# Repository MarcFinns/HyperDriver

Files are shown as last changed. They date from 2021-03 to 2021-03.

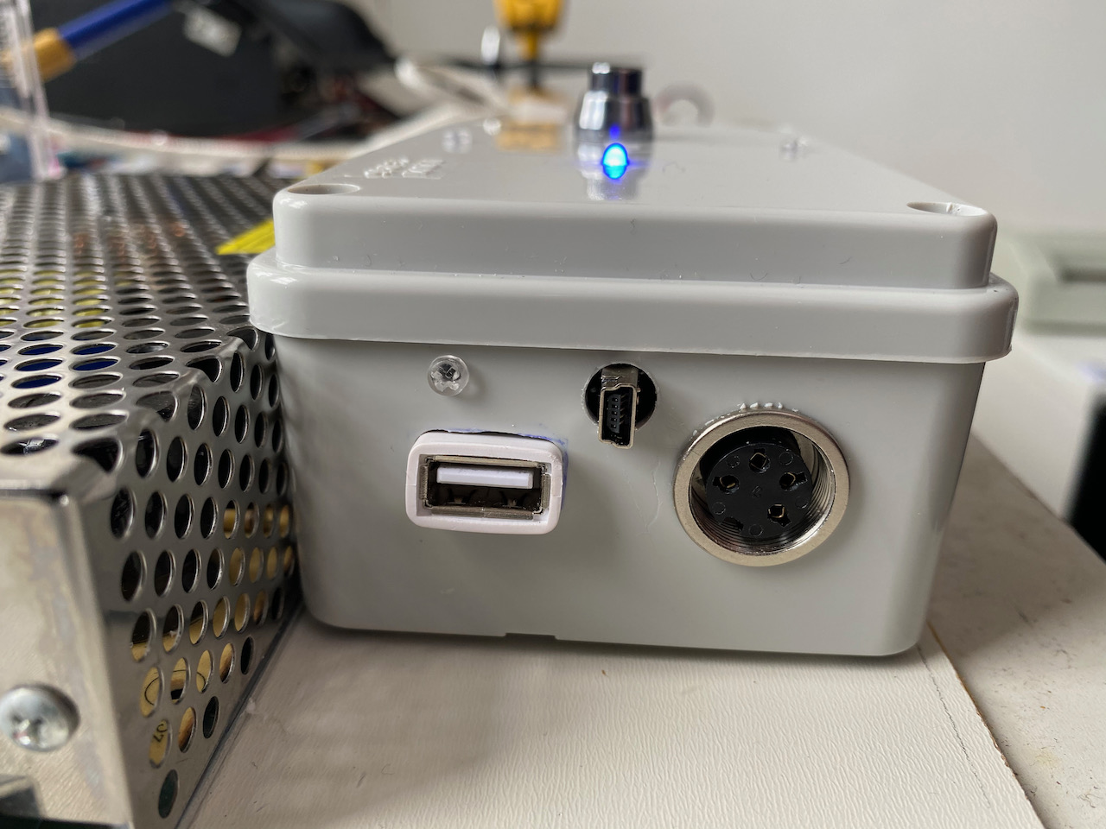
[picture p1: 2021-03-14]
Pictures/Box connections.jpeg

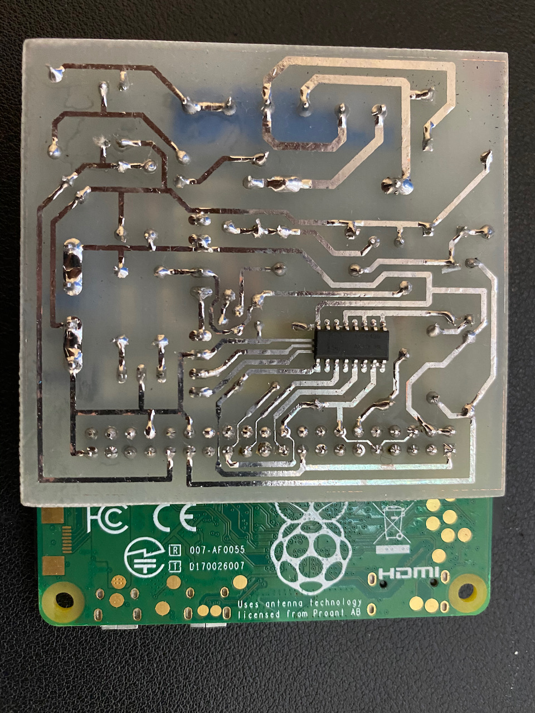
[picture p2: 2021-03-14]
Pictures/Board back.jpeg

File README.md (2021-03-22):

# HyperDriver
LED driver and power board for Hyperion (DYI Ambilight)

See short video: https://www.youtube.com/watch?v=JoaK5aRHBMA

After setting up hyperion I was annoyed by starting/stopping it manually every time.
My weekend project was to build a proper solution - with components I had in the drawer, which might explain some weird design choices.

The board does the following:

* Connects as a PI hat
* Powers the PI and the LED strip with the same power supply
* Provides 5V drivers / level adaptation for the APA 102 LED stripe
* Allows to turn the PI on by pushing a button
* With the same button, triggers a proper shutdown (no abrupt power cut)
* Connects to TV via USB and can start the PI when the TV turns on
* The PI can automatically shutdown when TV goes off (immediately or after X minutes)
* If the automatic turn on from TV is triggered, the PI can still be shut down via the button
* A 5V socket is available for a small fan, in case

The On/Off function is proper, meaning the power supply is truly disconnected from the mains when off.
I made sure that the PCB is single side and doable at home with some medium skills (e.g. i made it with toner transfer). 
I could not avoid one SMD but only because I did not have the through-hole part in the drawer. Convertinf the PCB to through hole is trivial.
The whole thing fits in a small electric junction box. See pictures.

**IMPORTANT DISCLAIMER:**<BR>
* This is **NOT** your typical 5V Arduino project. <BR>
* It is **NOT** breadboard friendly.<BR>
* Make it **ONLY** if you know what you are doing.<BR>
* Danger of electrocution

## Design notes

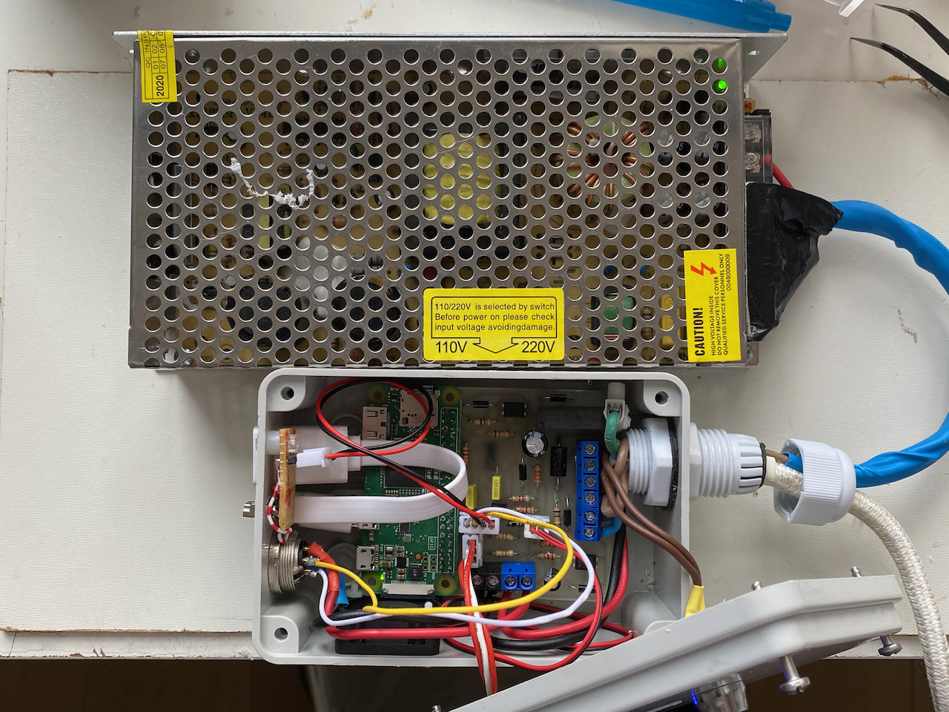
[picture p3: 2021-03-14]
Pictures/Box open and power supply.jpeg

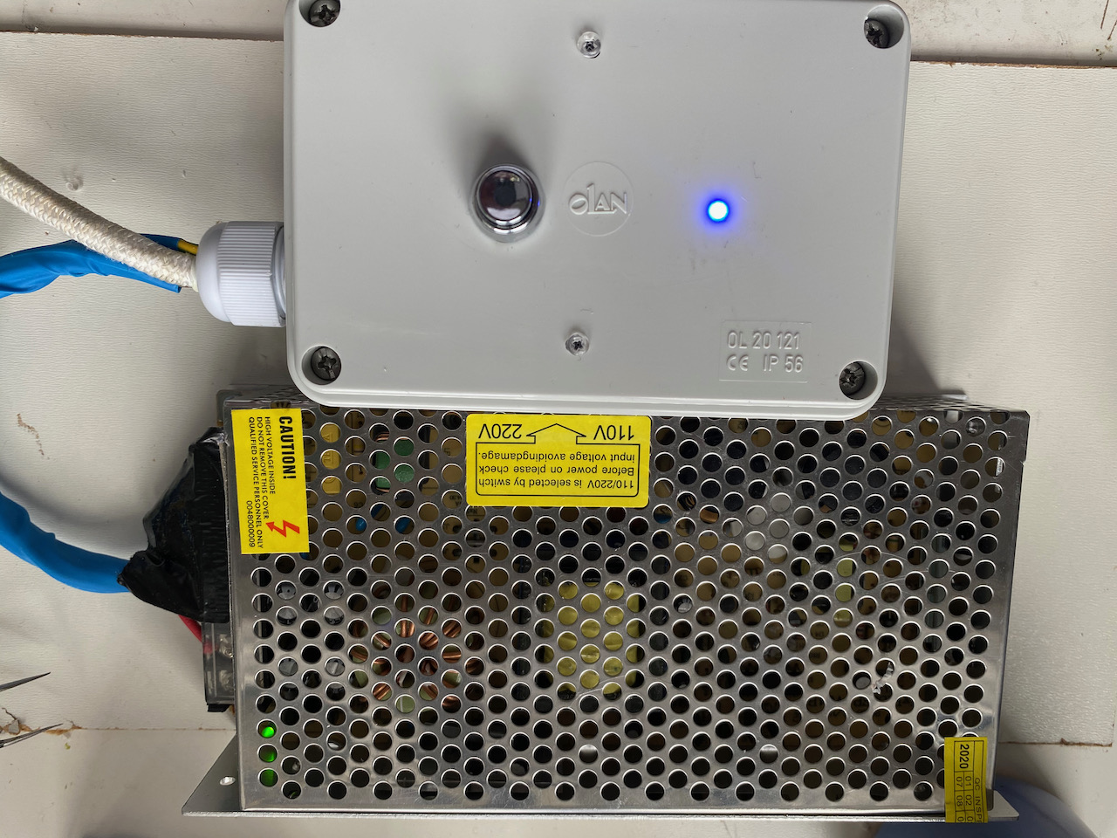
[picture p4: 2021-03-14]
Pictures/Box and power supply.jpeg

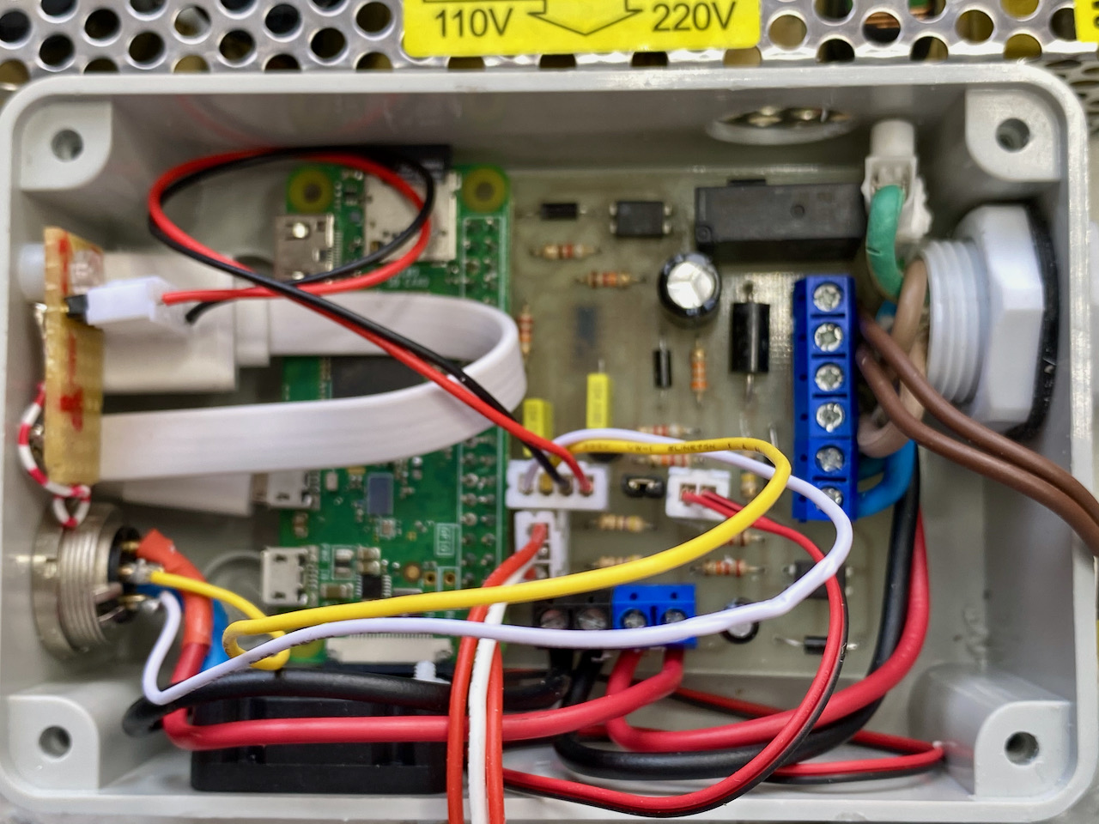
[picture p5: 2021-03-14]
Pictures/Box inside.jpeg

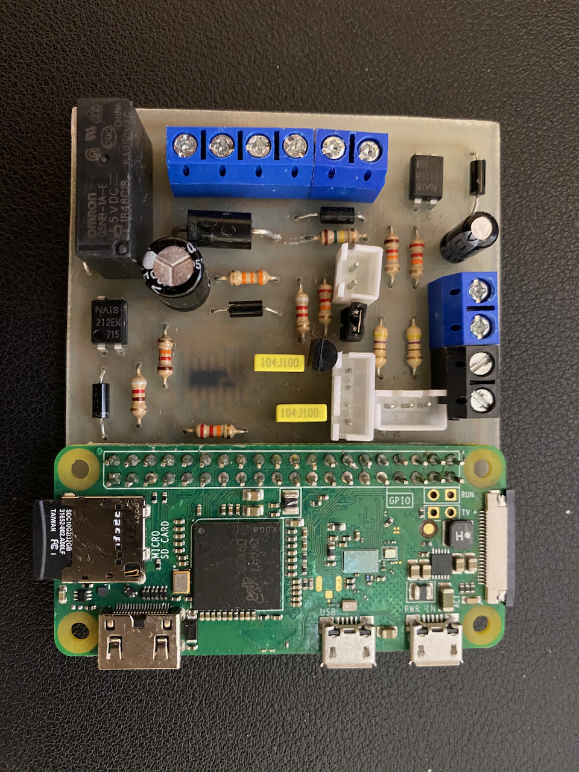
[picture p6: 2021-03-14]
Pictures/Board front.jpeg

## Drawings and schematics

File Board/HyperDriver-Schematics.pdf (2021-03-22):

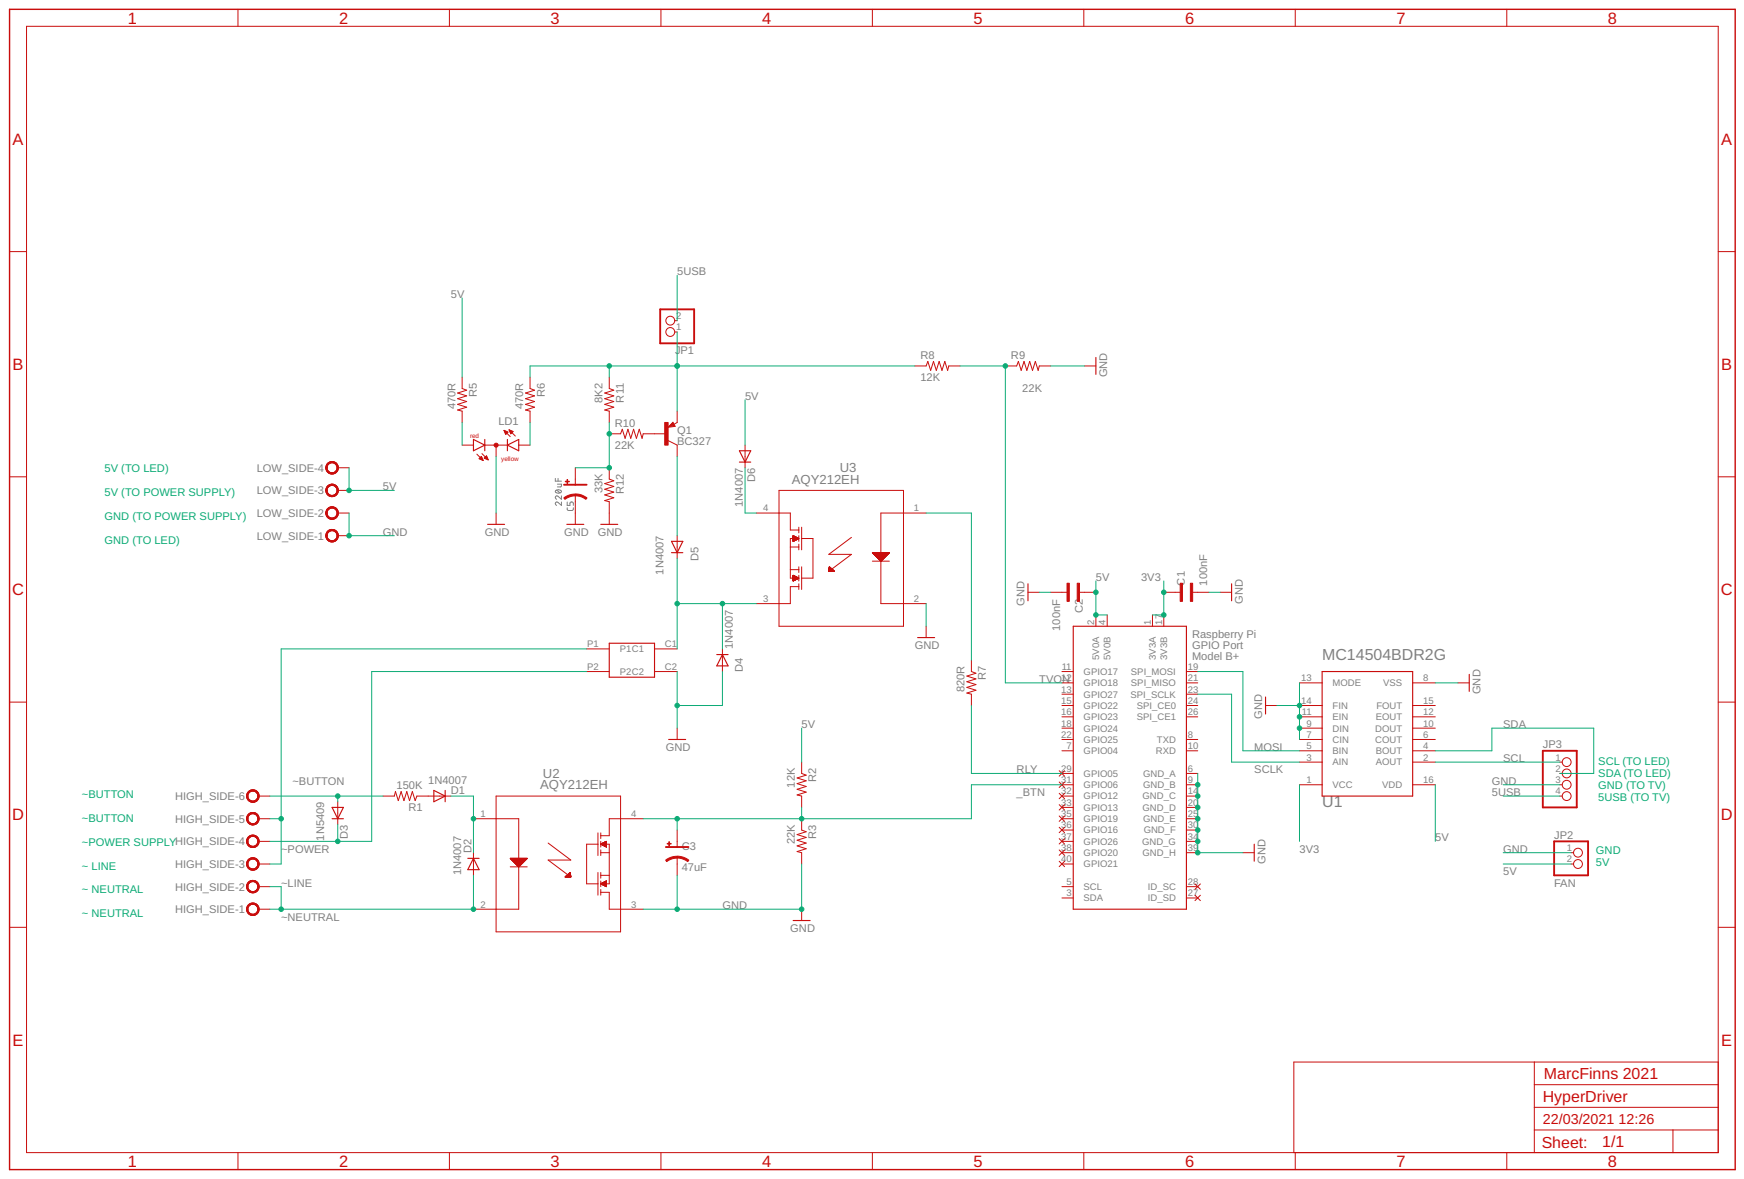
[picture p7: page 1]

5V (TO LED)
5V (TO POWER SUPPLY)
GND (TO POWER SUPPLY)
GND (TO LED)

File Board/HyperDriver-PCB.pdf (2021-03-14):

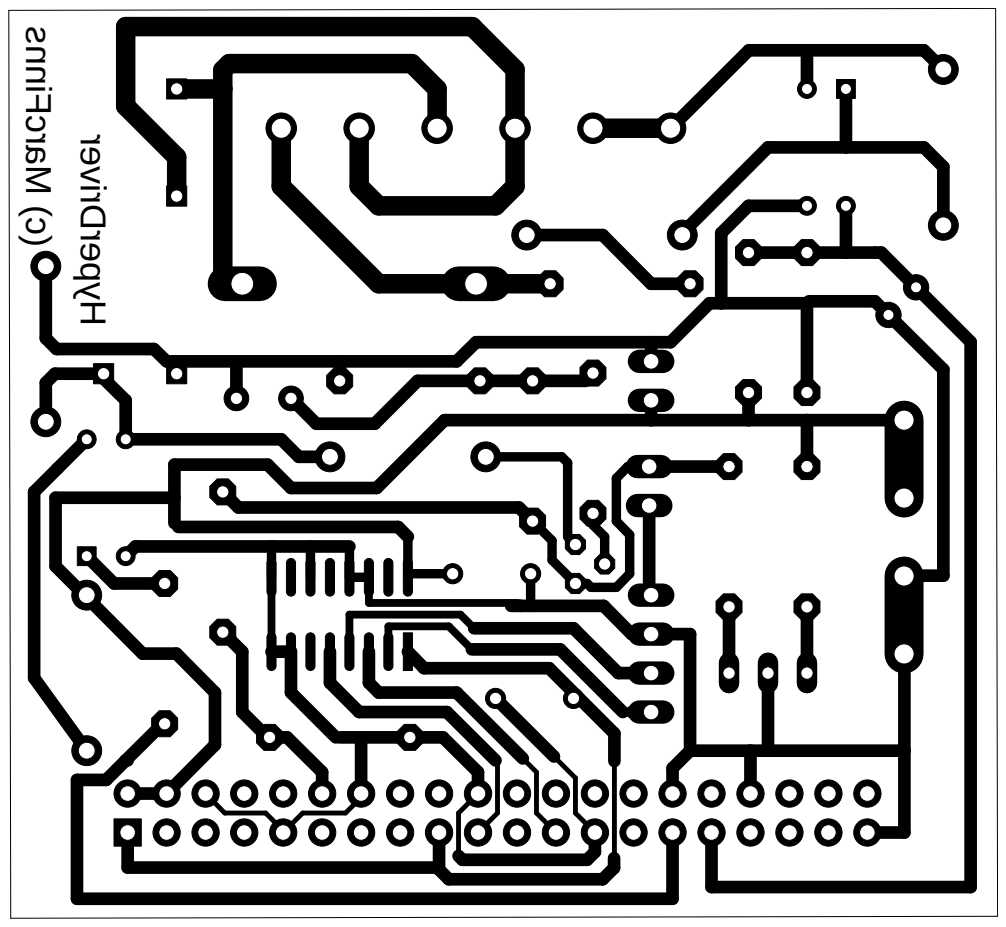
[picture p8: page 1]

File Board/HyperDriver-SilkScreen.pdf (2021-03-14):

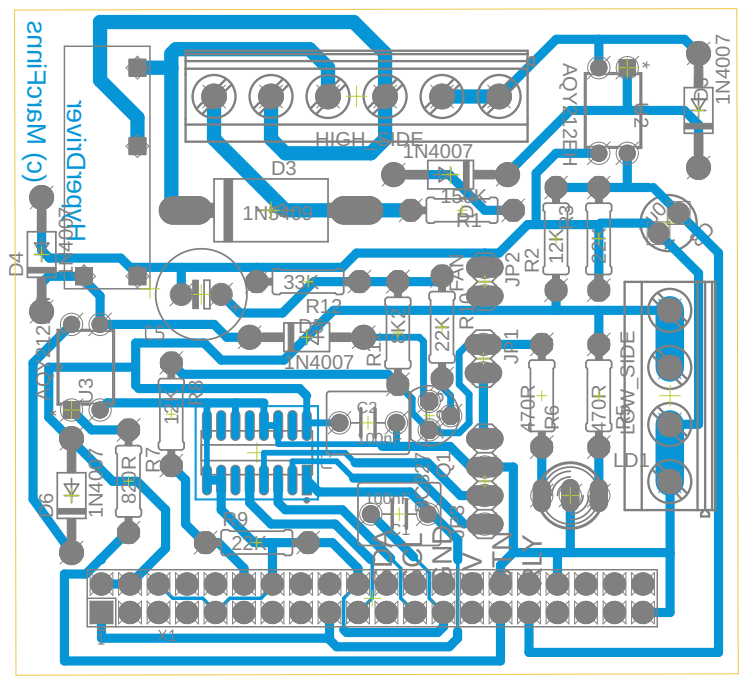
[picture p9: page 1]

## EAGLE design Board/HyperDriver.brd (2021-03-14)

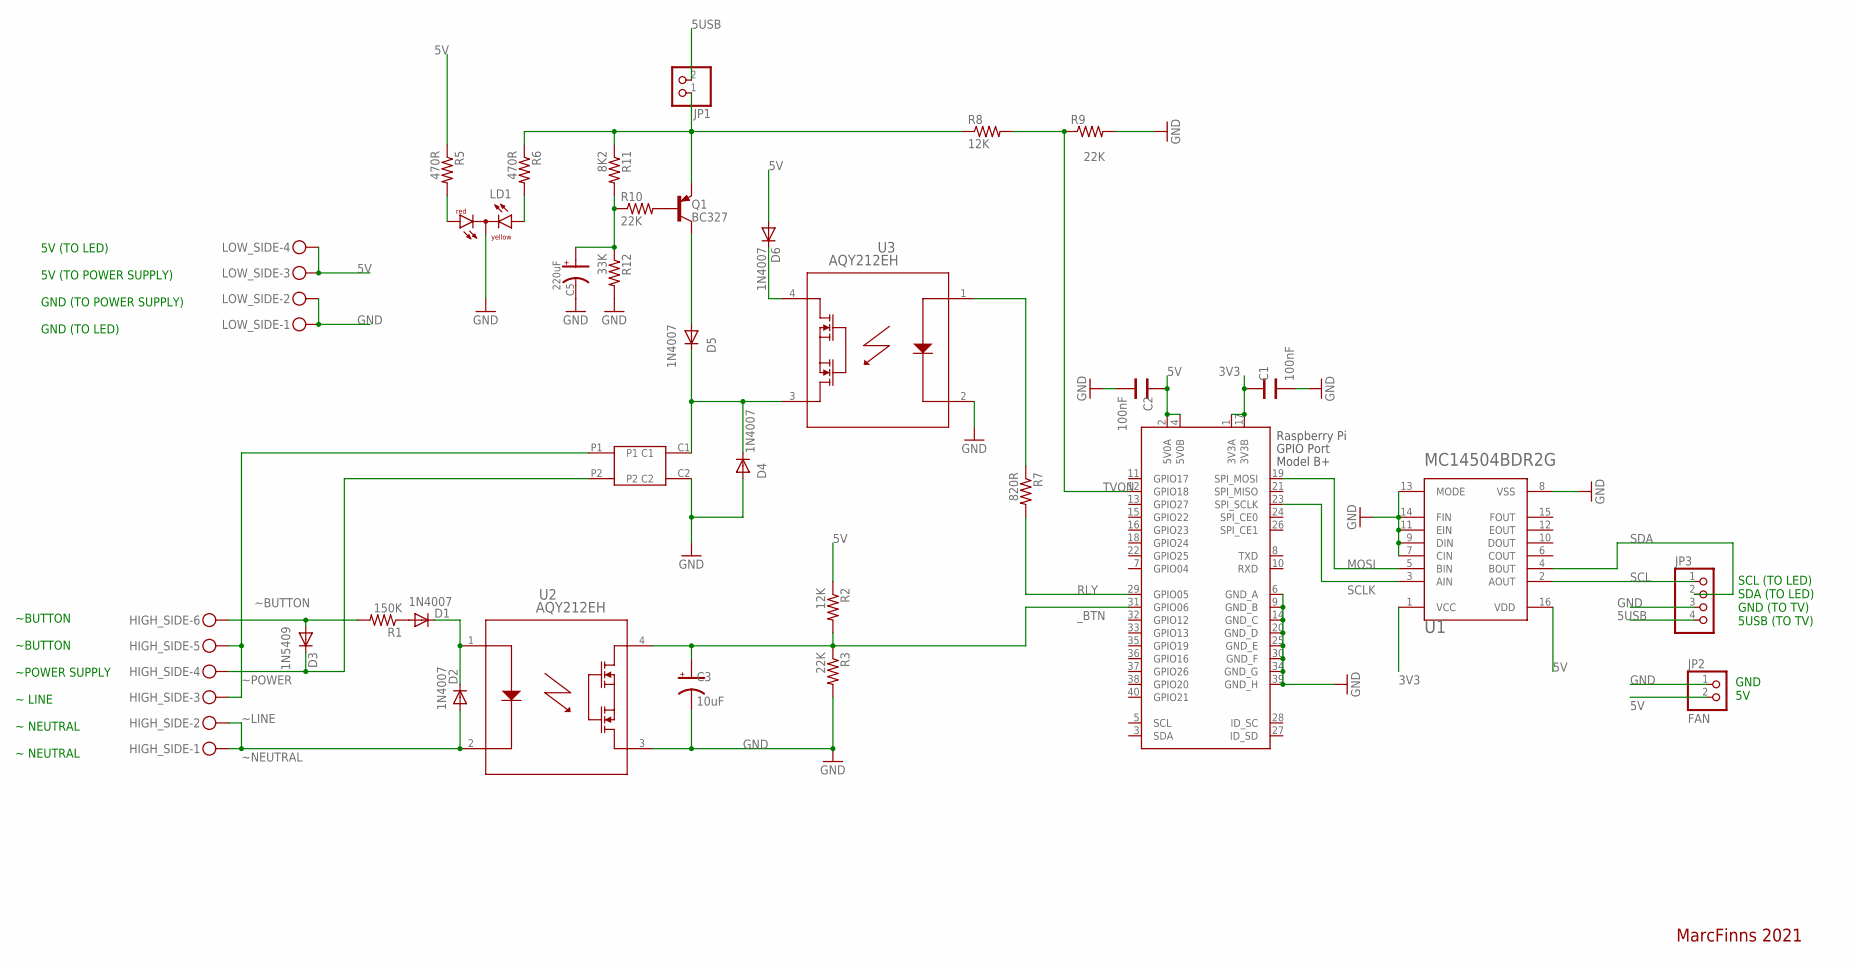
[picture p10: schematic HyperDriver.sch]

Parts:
C1, C2: 100nF; CAP-055X070
C3: 10uF; CAP-POL-025X50
C5: 220uF; CAP-POL-E3,5-8
D1, D2, D4, D5, D6: 1N4007; DO41-10
D3: 1N5409; DO201-15
G5NB_RELAY1: OMRON_G5NB_RELAY; G5NB_RELAY
HIGH_SIDE: MKDSN1,5/6-5,08
JP1: PINHD-1X2; 1X02
JP2: FAN; 1X02
JP3: PINHD-1X4; 1X04
LD1: DUOLED-RY-C; DUOLED-C-5MM
LOW_SIDE: MKDSN1,5/4-5,08
Q1: BC327; TO92
R1: 150K; 0207/9
R2, R8: 12K; 0207/9
R3, R9, R10: 22K; 0207/9
R5, R6: 470R; 0207/9
R7: 820R; 0207/9
R11: 8K2; 0207/9
R12: 33K; 0207/9
U1: ON_SEMICONDUCTOR_MC14504BDR2GON_SEMICONDUCTOR_MC1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; ON_SEMICONDUCTOR_MC14504BDR2G_1
U2, U3: AQY212EH; PAN_AQY21-DIP4_PAN
X1: RASPI_GPIO_B+#_PIN; RASPI_GPIO_B+_PIN

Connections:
3V3: C1.1, U1.1 (VCC), X1.1 (3V3A), X1.17 (3V3B)
5USB: JP1.2, JP3.4
5V: C2.1, D6.A, JP2.2, LOW_SIDE.3, LOW_SIDE.4, R2.1, R5.1, U1.16 (VDD), X1.2 (5V0A), X1.4 (5V0B)
GND: C1.2, C2.2, C3.C, C5.C, D4.A, G5NB_RELAY1.C2, JP2.1, JP3.3, LD1.C, LOW_SIDE.1, LOW_SIDE.2, R3.2, R9.2, R12.2, U1.7 (CIN), U1.8 (VSS), U1.9 (DIN), U1.11 (EIN), U1.13 (MODE), U1.14 (FIN), U2.3, U3.2, X1.6 (GND_A), X1.9 (GND_B), X1.14 (GND_C), X1.20 (GND_D), X1.25 (GND_E), X1.30 (GND_F), X1.34 (GND_G), X1.39 (GND_H)
J_5USB: JP1.1, Q1.1 (E), R6.1, R8.1, R11.1
MOSI: U1.5 (BIN), X1.19 (SPI_MOSI)
unnamed: LD1.AR, R5.2
unnamed: LD1.AX (AY), R6.2
unnamed: D6.C, U3.4
unnamed: Q1.2 (B), R10.2
unnamed: C5.A, R10.1, R11.2, R12.1
unnamed: D1.C, D2.C, U2.1
unnamed: R7.1, U3.1
unnamed: D4.C, D5.C, G5NB_RELAY1.C1, U3.3
unnamed: D5.A, Q1.3 (C)
unnamed: D1.A, R1.1
RLY: R7.2, X1.29 (GPIO05)
SCL: JP3.1, U1.2 (AOUT)
SCLK: U1.3 (AIN), X1.23 (SPI_SCLK)
SDA: JP3.2, U1.4 (BOUT)
TVON: R8.2, R9.1, X1.12 (GPIO18)
_BTN: C3.A, R2.2, R3.1, U2.4, X1.31 (GPIO06)
~BUTTON: D3.A, HIGH_SIDE.6, R1.2
~LINE: G5NB_RELAY1.P1, HIGH_SIDE.3, HIGH_SIDE.5
~NEUTRAL: D2.A, HIGH_SIDE.1, HIGH_SIDE.2, U2.2
~POWER: D3.C, G5NB_RELAY1.P2, HIGH_SIDE.4

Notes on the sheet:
SCL (TO LED) SDA (TO LED) GND (TO TV) 5USB (TO TV)
GND 5V
~BUTTON ~BUTTON ~POWER SUPPLY ~ LINE ~ NEUTRAL ~ NEUTRAL
5V (TO LED) 5V (TO POWER SUPPLY) GND (TO POWER SUPPLY) GND (TO LED)
MarcFinns 2021

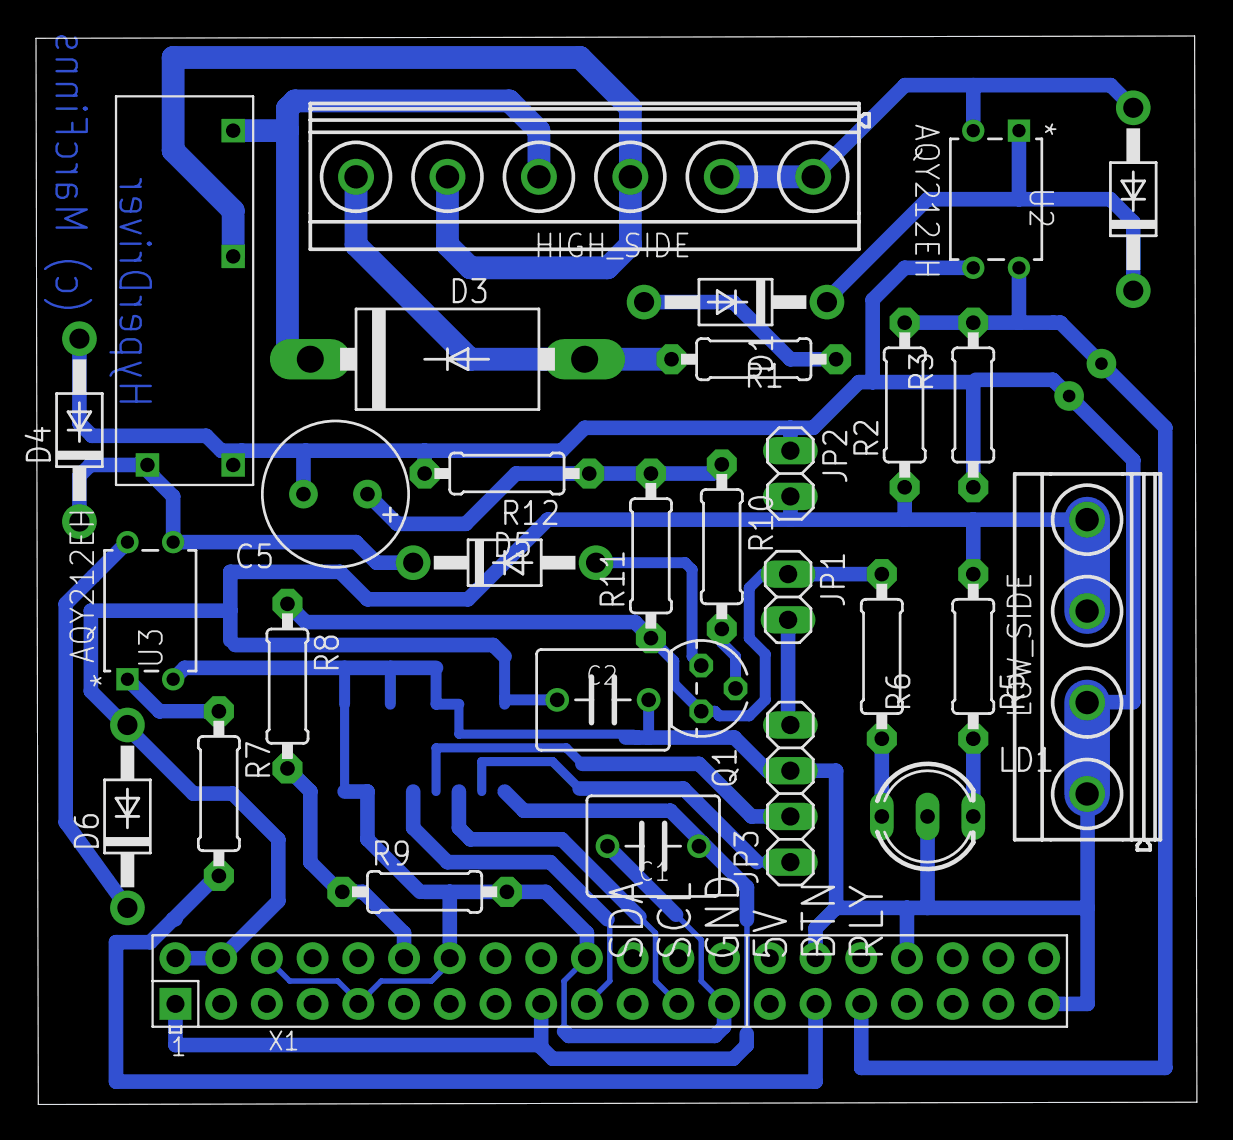
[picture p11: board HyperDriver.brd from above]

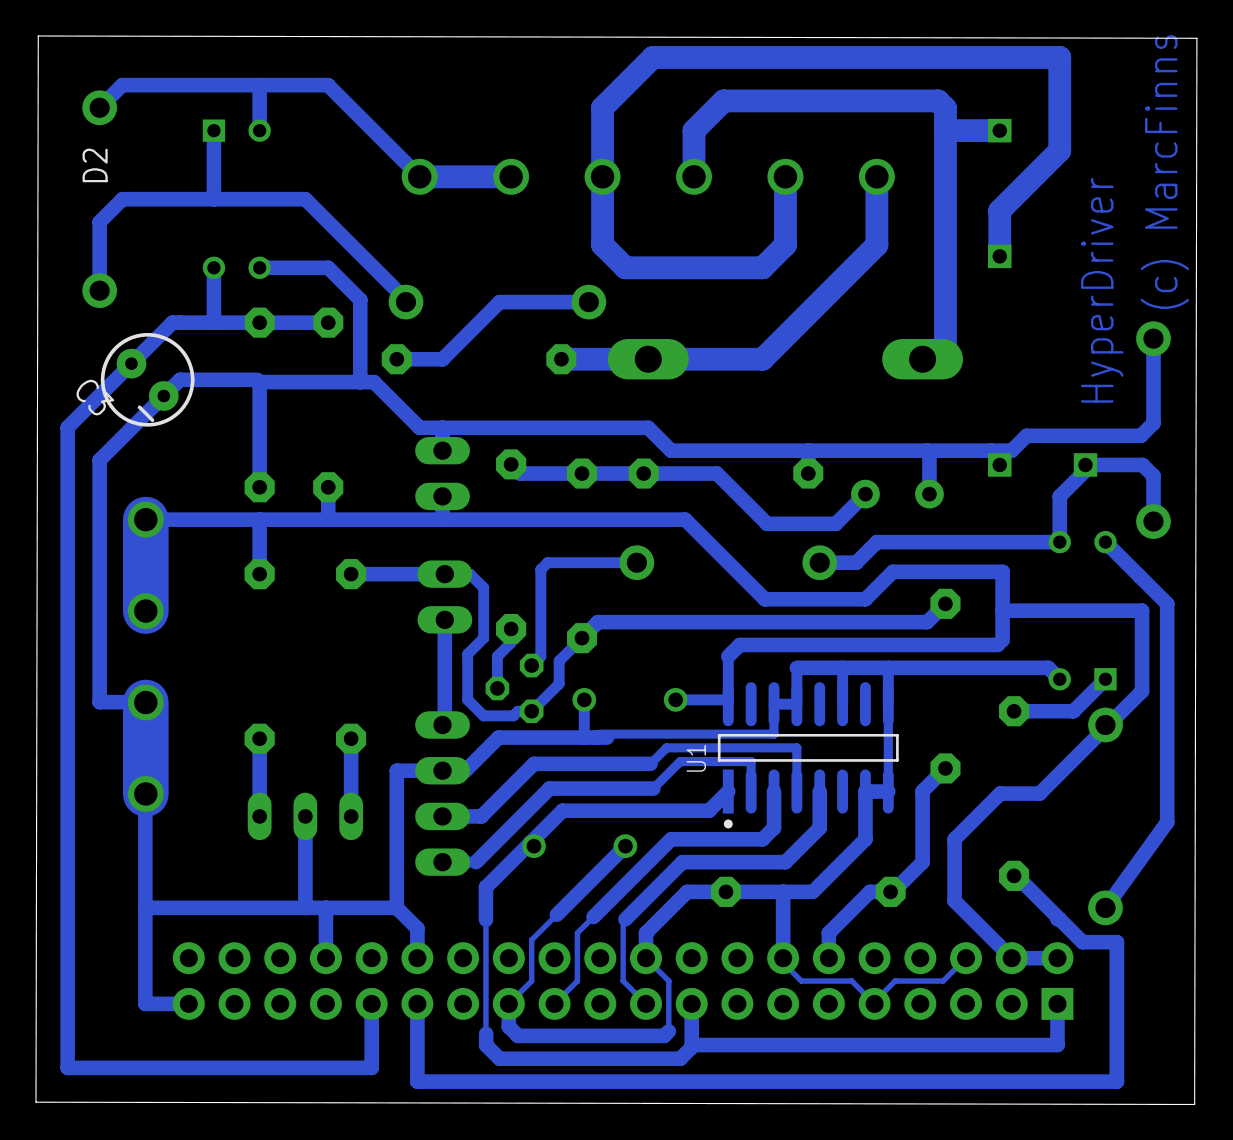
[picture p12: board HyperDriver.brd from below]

Board: 2 copper layers, 64.5 x 59.4 mm, 33 parts (2 on the bottom side), 26 nets.

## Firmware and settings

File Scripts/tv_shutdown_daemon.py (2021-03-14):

#!/usr/bin/python
#-------------------------------------------------------------------------------
# Name:         Shutdown Daemon
#
# Purpose:      This program gets activated at the end of the boot process by
#               cron. (@ reboot sudo python /home/pi/shutdown_daemon.py)
#               It monitors a button press. If the user presses the button, we
#               Halt the Pi, by executing the poweroff command.
#
#               The power to the Pi will then be cut when the Pi has reached the
#               poweroff state (Halt).
#               To activate a gpio pin with the poweroff state, the
#               /boot/config.txt file needs to have :
#               dtoverlay=gpio-poweroff,gpiopin=27
#
# Author:      Paul Versteeg
#
# Created:     15-06-2015, revised on 18-12-2015
# Copyright:   (c) Paul 2015
# Licence:     <your licence>
#-------------------------------------------------------------------------------

import RPi.GPIO as GPIO
import subprocess
import time

GPIO.setmode(GPIO.BCM) # use GPIO numbering
GPIO.setwarnings(False)

# I use the following two GPIO pins because they are next to each other,
# and I can use a two pin header to connect the switch logic to the Pi.
TV = 18    # GPIO-18 TV power interrupt to shutdown procedure

# use a weak pull_up to create a high
GPIO.setup(TV, GPIO.IN, pull_up_down=GPIO.PUD_UP)

def main():

    while True:
        # set an interrupt on a falling edge and wait for it to happen
        GPIO.wait_for_edge(TV, GPIO.FALLING)
	time.sleep(60)
	if GPIO.input(TV):
    		print('Input was HIGH, TV still ON')
       	else:
    		print('Input was LOW, TV is effectively OFF')
		subprocess.call(['poweroff'], shell=True, \
                        stdout=subprocess.PIPE, stderr=subprocess.PIPE)
if __name__ == '__main__':
    main()

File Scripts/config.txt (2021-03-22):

# HyperDriver configuration
# NOTE: First line is not strictly necessary, but speeds up relay activation on button press
gpio=5=op,dh                                                                              
dtoverlay=gpio-poweroff,gpiopin=5,active_low="y"
dtoverlay=gpio-shutdown,gpio_pin=6,active_low=1
